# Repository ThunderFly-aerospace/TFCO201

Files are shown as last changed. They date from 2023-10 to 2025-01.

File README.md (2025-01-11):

# TFCO201 - ThunderFly airborne CO2 concentration sensor



The TFCO201 [carbon dioxide gas](https://en.wikipedia.org/wiki/Carbon_dioxide) sensor offers flexible integration options. It can be directly connected to a Pixhawk autopilot with PX4 firmware or used as a sensor for the [TF-ATMON monitoring system](https://www.thunderfly.cz/tf-atmon.html).

Sensors mounted on UAVs can be used for a variety of purposes. TFCO201 can measure CO2 concentrations in parallel with air temperature and humidity, which can be used for meteorological purposes. It could also be used to determine the presence of wildfires.

TFCO201 sensor with cable

## Applications

In combination with the [TF-ATMON system](https://www.thunderfly.cz/tf-atmon.html), the sensor could be used in various applications. Here are a few examples. 

### Atmospheric sounding

The TFCO201 sensor could be used for [direct atmospheric sounding](https://en.wikipedia.org/wiki/Atmospheric_sounding). Here is an example of measured data taken by [TF-G2 autogyro](https://www.thunderfly.cz/tf-g2.html).

### Locating sources of atmospheric pollution (Urban Air Quality Monitoring)

A drone with a CO2 sensor can monitor carbon dioxide levels in densely populated urban areas, such UAVs can collect data on CO2 concentrations across different parts of the city, aiding authorities in identifying and addressing areas with high emissions. This data can be utilized for green space planning, improving urban transportation, and informing residents about air quality.

### Ecosystem Change Observation 
An unmanned system with a CO2 sensor can monitor changes in CO2 levels in various ecosystems, such as forests, wetlands, or agricultural lands. This information is crucial for scientists studying the impact of climate change on different types of environments and aids in predicting future ecological changes or impact mitigation methods. 

### Industrial Emission Control 
Industrial areas often contribute significantly to total CO2 emissions. A UAV with a CO2 sensor can effectively monitor and map emissions from factories, power plants, and other industrial facilities. This data can be used for emission regulation and developing strategies to reduce the carbon footprint of industrial areas.

## Where to get it?

The TFCO201 is commercially available from [ThunderFly s.r.o.](https://www.thunderfly.cz/). For a commercial quotation, contact us by email at sale@thunderfly.cz or shop at our [Tindie store](https://www.tindie.com/stores/thunderfly/).

## Parameters

| Parameter | Value | Description |
|---|---|---|
| Sensing element | [SCD41](https://sensirion.com/media/documents/E0F04247/631EF271/CD_DS_SCD40_SCD41_Datasheet_D1.pdf) | Other possible sensors SCD40, SCD42 |
| Typical accuracy | ± (50 ppm + 5% of reading) | 400 ppm – 2’000 ppm  |
| Humidity measurement accuracy | ± 9 % RH | -10 °C – 60 °C, 0 %RH – 100 %RH  |
| Temperature measurement accuracy | ± 1.5 °C | -10 °C – 60 °C |
| Repeatability | ± 10 ppm |  |
| Operating temperature range| -10 °C – 60 °C |  |
| Operating humidity range| 0 %RH – 100 %RH | |
| I2C connector | 4-pin JST-GH | The second connector could be installed on the opposite side |
| I2C address | 0x62 | can be changed by using the [TFI2CADT01](https://github.com/ThunderFly-aerospace/TFI2CADT01) |
| Storage temperature range| -20 °C - +40 °C |  |
| Operational input voltage | 3.6 - 5.4V | Overvoltage internally protected by zener diode |
| Mass | 3 g | PCB, without cabling |
| Dimensions | 30 x 15 x 6.5 mm |  PCB |
| Weather resistance | IP40 | External connectors fully occupied.  |

## Schematics

Schematics

## Usage in PX4
~~The sensor is currently supported by the PX4 autopilot. Multiple sensors can be connected to one autopilot. The measured data are immediately sent to the ground station and they are also logged in the onboard ulog file.~~

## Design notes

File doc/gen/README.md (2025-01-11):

# PCB

Board size: 30.0x15.0 mm (1.18x0.59 inches)

- This is the size of the rectangle that contains the board
- Thickness: 0.89 mm (35 mils)
- Material: FR4
- Finish: HAL lead-free
- Layers: 2
- Copper thickness: 35 µm

Solder mask: TOP / BOTTOM

- Color: Green

Silk screen: TOP / BOTTOM

- Color: White

Stackup:

| Name | Type | Color | Thickness [µm]| Material | Er | Loss tan |
|---|---|---|---|---|---|---|
| F.SilkS | Top Silk Screen | | | | | |
| F.Mask | Top Solder Mask | Green | 10 | | | |
| F.Cu | copper | | 35 | | | |
| dielectric 1 | core | | 800 | FR4 | 4.5 | 0.020 |
| B.Cu | copper | | 35 | | | |
| B.Mask | Bottom Solder Mask | Green | 10 | | | |
| B.SilkS | Bottom Silk Screen | | | | | |

# Important sizes

Clearance: 0.2 mm (8 mils)

Track width: 0.3 mm (12 mils)

- By design rules: 0.15 mm (6 mils)

Drill: 0.5 mm (20 mils)

- Vias: 0.5 mm (20 mils) [Design: 0.4 mm (16 mils)]
- Pads: 3.0 mm (118 mils)
- The above values are real drill sizes, they add 0.1 mm (4 mils) to plated holes (PTH)

Via: 0.8/0.4 mm (31/16 mils)

- By design rules: 0.4/0.3 mm (16/12 mils)
- Micro via: yes [0.2/0.1 mm (8/4 mils)]
- Buried/blind via: yes
- Total: 28 (thru: 28 buried/blind: 0 micro: 0)

Outer Annular Ring: 0.15 mm (6 mils)

- By design rules: N/A mm (N/A mils)

Eurocircuits class: 4B
- Using min drill 0.5 mm for an OAR of 0.15 mm

# General stats

Components count: (SMD/THT)

- Top: 1/6 (SMD + THT)
- Bottom: 12/0 (SMD)

Defined tracks:

- 0.3 mm (12 mils)
- 0.4 mm (16 mils)
- 0.5 mm (20 mils)
- 1.0 mm (39 mils)

Used tracks:

- 0.3 mm (12 mils) (22) defined: yes
- 0.4 mm (16 mils) (87) defined: yes

Defined vias:

Used vias:

- 0.8/0.4 mm (31/16 mils) (Count: 28, Aspect: 1.1 A) defined: no

Holes (excluding vias):

- 3.0 mm (118 mils) (6)

Oval holes:

Drill tools (including vias and computing adjusts and rounding):

- 0.5 mm (20 mils) (28)
- 3.0 mm (118 mils) (6)

Solder paste stats:

Using a paste with 87.75 % alloy, that has an specific gravity for the alloy of 7.4 g/cm³
and 1.0 g/cm³ for the flux. This paste has an specific gravity of  4.15 g/cm³.

The stencil thickness is  0.12 mm.

| Side | Pads with paste | Area [mm²] | Paste [g] |
|---|---|---|---|
| Top | 6 | 9.28 | 0.05 |
| Bottom | 53 | 75.30 | 0.37 |
| Total  | 59 | 84.58 | 0.42 |

Note: this is just an approximation to the theoretical value. Margins of the solder mask and waste aren't computed.

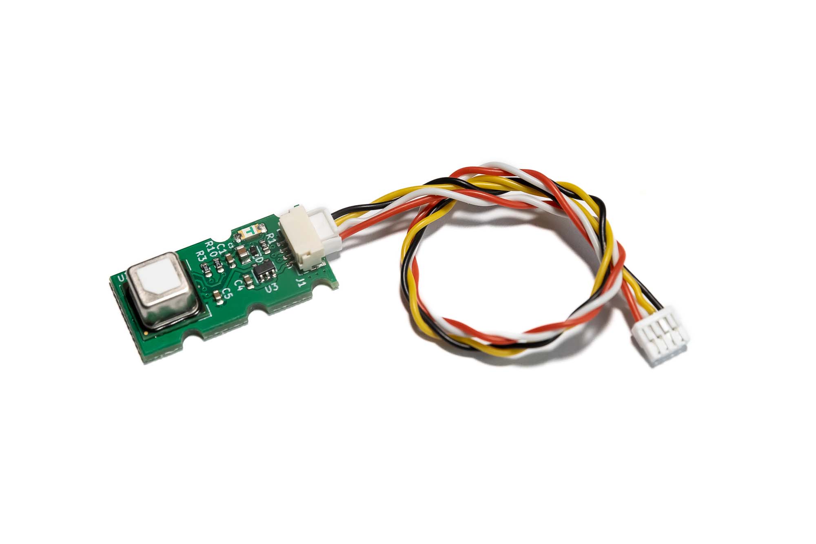
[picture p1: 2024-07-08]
doc/img/TFCO201-small.jpg

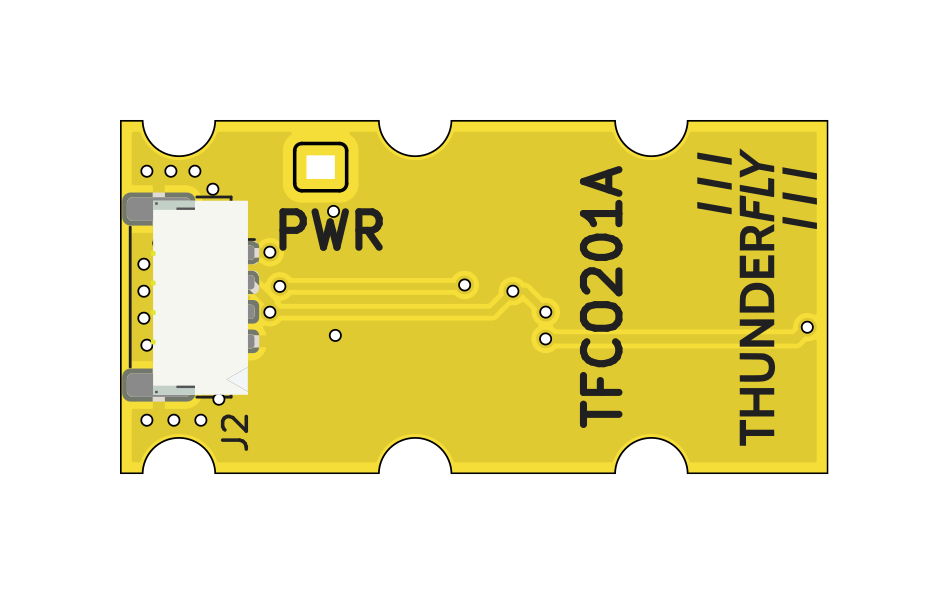
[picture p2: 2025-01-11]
doc/gen/img/TFCO201-top.png

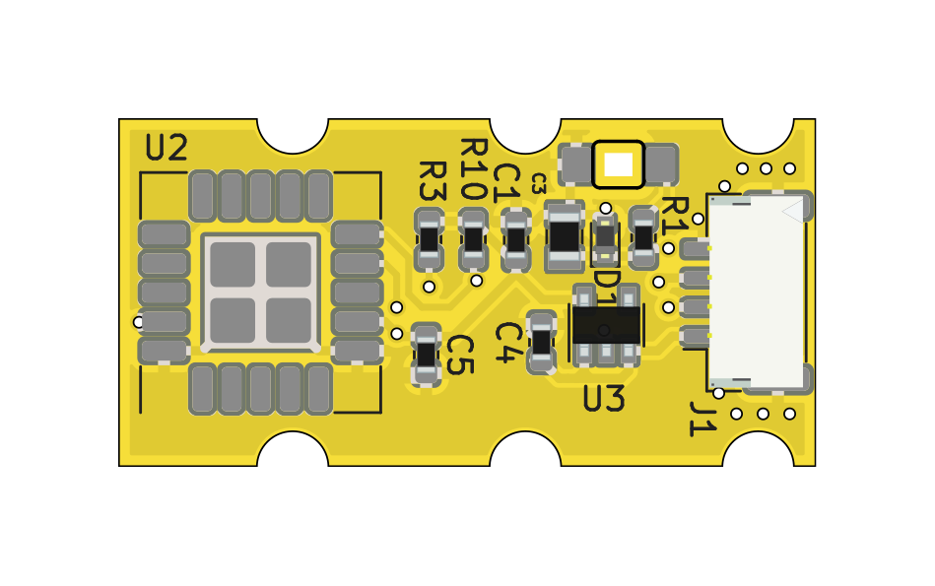
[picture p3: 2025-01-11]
doc/gen/img/TFCO201-bottom.png

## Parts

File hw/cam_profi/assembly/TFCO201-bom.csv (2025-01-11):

Component | Description | Part | References | Value | Footprint | Quantity Per PCB | Datasheet | ust_id
1 | Unpolarized capacitor | C | C4C5 | 100nF | SMD-0603 | 2 | ~ | 5c70984812875079b91f8bf2
2 | Unpolarized capacitor | C | C1 | 1uF | SMD-0603 | 1 | ~ | 5c70984812875079b91f8bc2
3 | Unpolarized capacitor | C | C3 | 10uF | SMD-0805 | 1 | ~ | 5c70984812875079b91f8bbd
4 |  | D_ZENER | D1 | BZX585-B5V6.115 | D_SOD-523 | 1 |  | 60879d38128750769ee58e48
5 | Light emitting diode | LED | D2 | LED GREEN | LED_1206_mill | 1 | ~ | 5c70984412875079b91f8895
6 |  | SM04B-GHS-TB | J1J2 | SM04B-GHS-TB | JST_GH_SM04B-GHS-TB_1x04-1MP_P1.25mm_Horizontal | 2 |  | 5c86273d1287500b4e0280be
7 | Resistor | R | R1 | 180R | SMD-0603 | 1 | ~ | 5c70984512875079b91f8957
8 | Resistor | R | R3R10 | 10k | SMD-0603 | 2 | ~ | 5c70984512875079b91f8962
9 | 300mA Low-dropout Voltage Regulator, Vout 3.3V, Vin up to 5.5V, SOT-23 | MIC5504-3.3YM5 | U3 | MIC5504-3.3YM5 | SOT-23-5 | 1 | http://ww1.microchip.com/downloads/en/DeviceDoc/MIC550X.pdf | 5c7255e81287500b4e112ea2
10 | Photoacoustic CO2 sensor, 40 000 ppm, I2C, 2.4-5.5 V, High accuracy 400 - 5000 ppm | SCD41-D-R2 | U2 | SCD41-D-R2 | Sensirion_SCD4x-1EP_10.1x10.1mm_P1.25mm_EP4.8x4.8mm | 1 | https://sensirion.com/media/documents/E0F04247/631EF271/CD_DS_SCD40_SCD41_Datasheet_D1.pdf

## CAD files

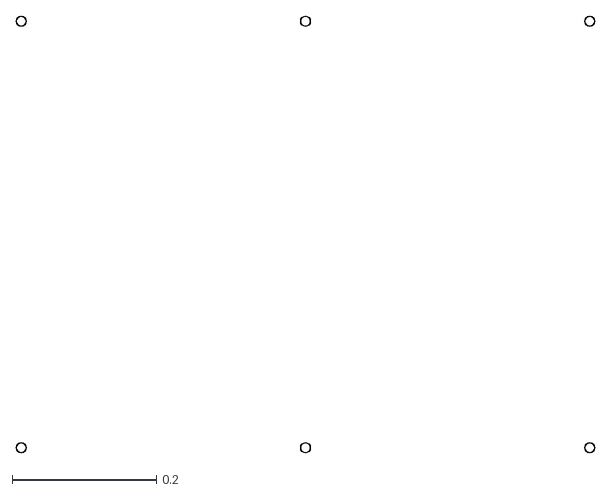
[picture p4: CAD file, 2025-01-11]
doc/gen/dxf/TFCO201-Margin.dxf
0.801 x 0.604

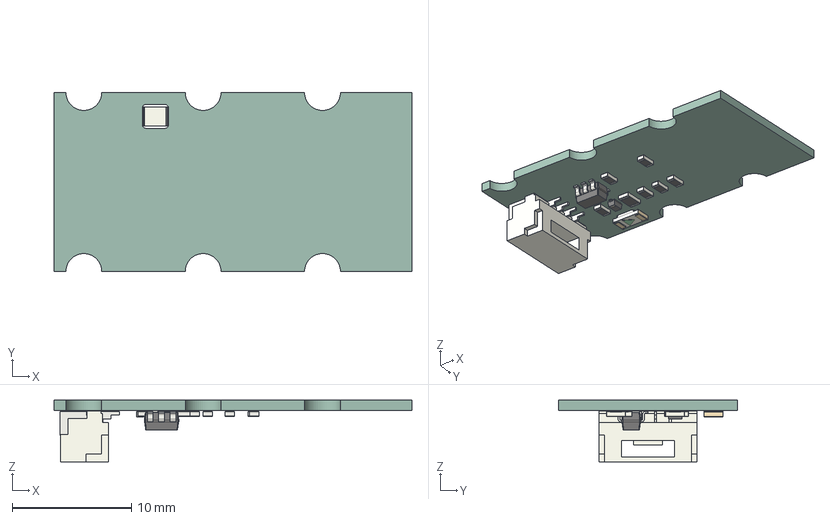
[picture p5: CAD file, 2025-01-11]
doc/gen/TFCO201.step
30.0 x 15.0 x 5.18 mm
LED_1206_3216Metric
R_0603_1608Metric x 6
D_SOD_523
JST_SM04B_GHS_TB
R_0805_2012Metric
SOT_23_5
kibot_szv15d0n_PCB

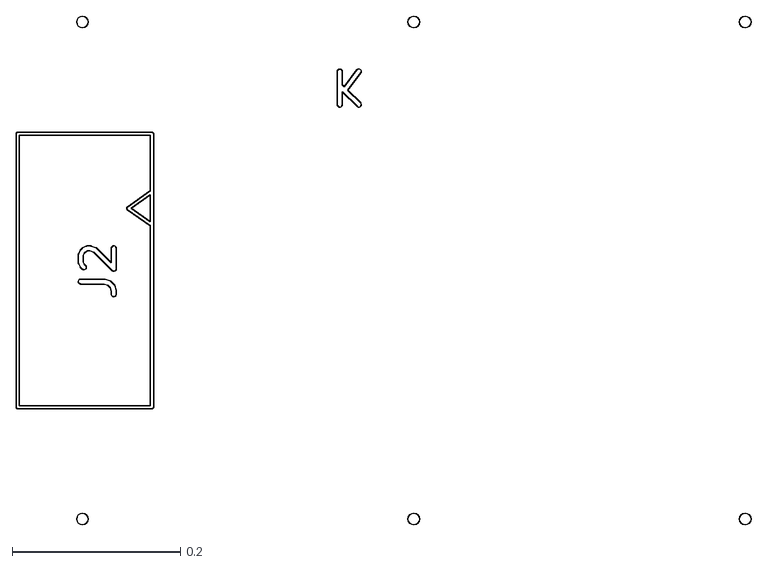
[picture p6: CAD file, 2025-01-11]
doc/gen/dxf/TFCO201-F_Fab.dxf
0.873 x 0.604

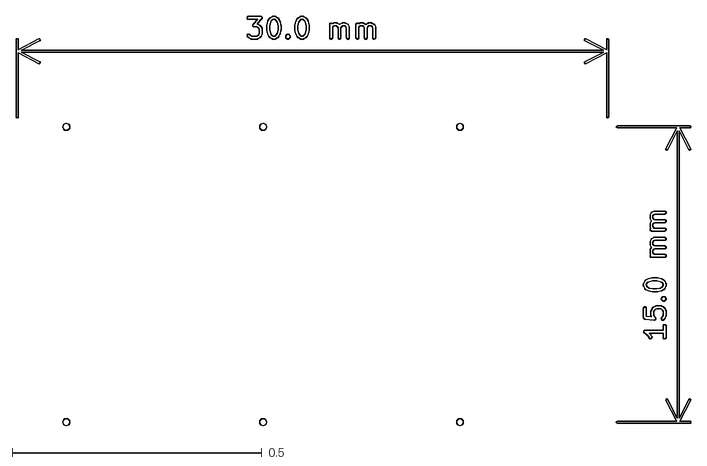
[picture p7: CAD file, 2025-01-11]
doc/gen/dxf/TFCO201-User_Drawings.dxf
1.35 x 0.818

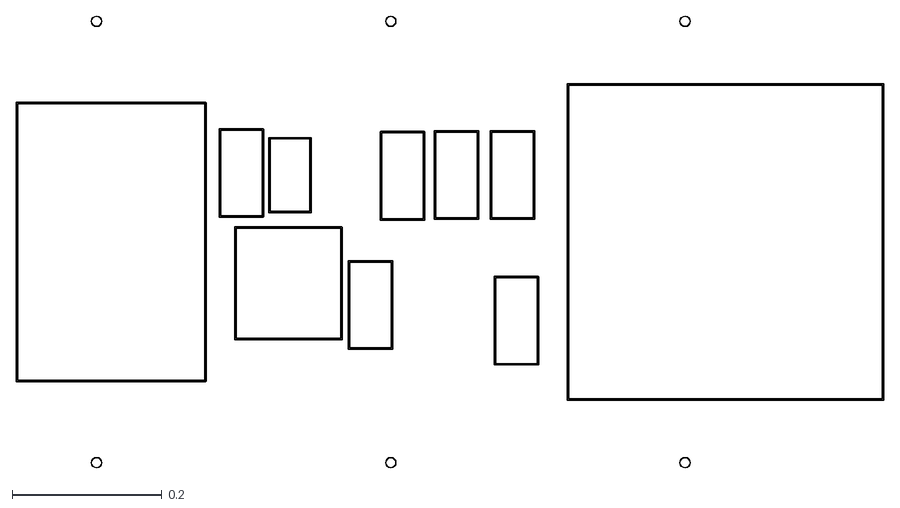
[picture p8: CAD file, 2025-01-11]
doc/gen/dxf/TFCO201-B_Courtyard.dxf
1.16 x 0.604

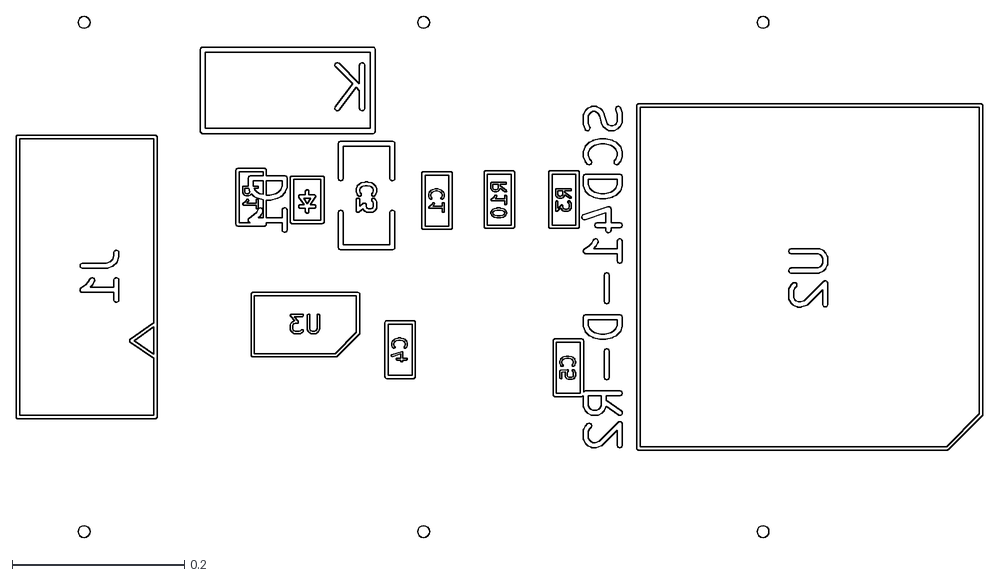
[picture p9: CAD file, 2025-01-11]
doc/gen/dxf/TFCO201-B_Fab.dxf
1.12 x 0.604

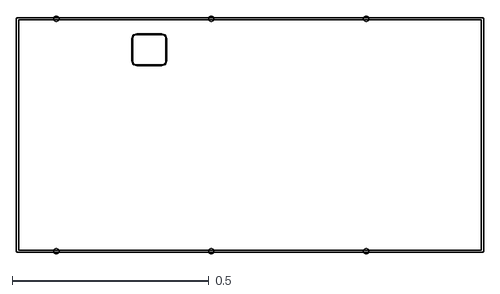
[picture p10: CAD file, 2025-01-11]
doc/gen/dxf/TFCO201-Edge_Cuts.dxf
1.19 x 0.604

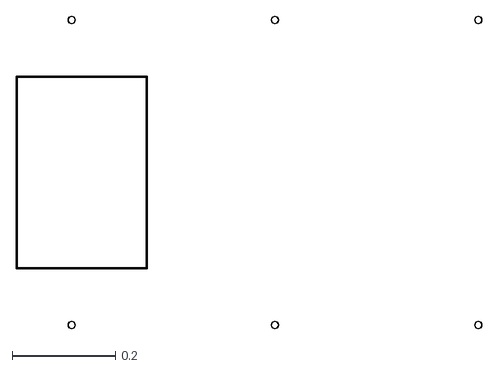
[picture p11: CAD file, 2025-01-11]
doc/gen/dxf/TFCO201-F_Courtyard.dxf
0.902 x 0.604

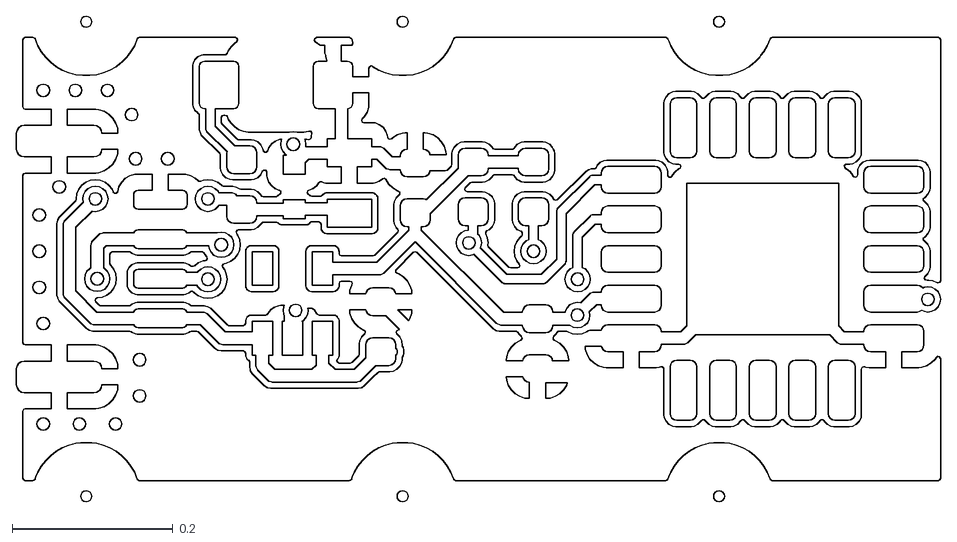
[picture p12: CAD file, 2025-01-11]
doc/gen/dxf/TFCO201-B_Cu.dxf
1.15 x 0.604

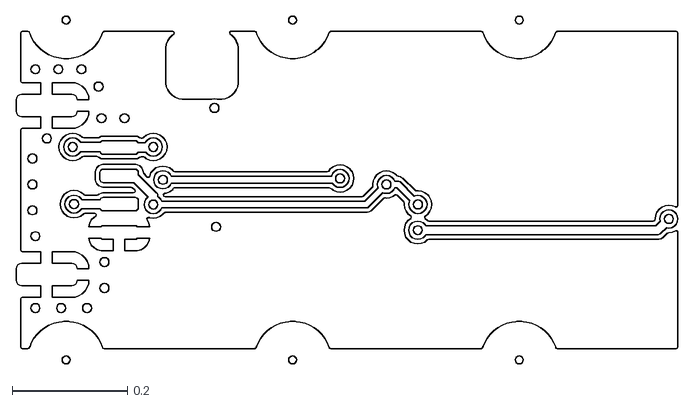
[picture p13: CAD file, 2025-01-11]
doc/gen/dxf/TFCO201-F_Cu.dxf
1.15 x 0.604

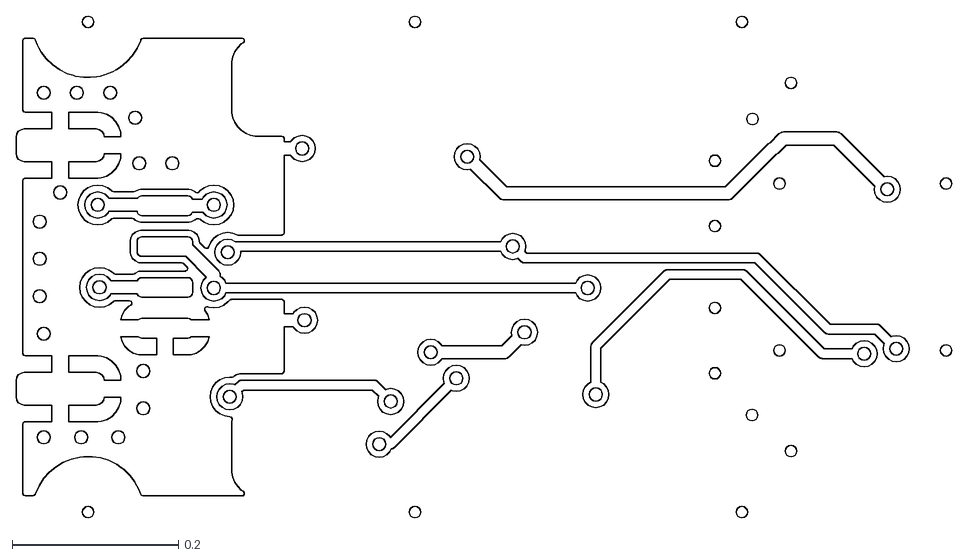
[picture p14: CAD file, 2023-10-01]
doc/gen/dxf/TFHT01-F_Cu.dxf
1.13 x 0.604

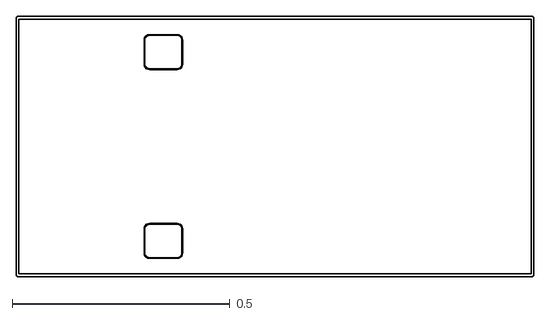
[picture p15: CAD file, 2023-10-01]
doc/gen/dxf/TFHT01-Edge_Cuts.dxf
1.19 x 0.596

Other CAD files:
doc/gen/dxf/TFCO201-B_Mask.dxf
doc/gen/dxf/TFCO201-B_Paste.dxf
doc/gen/dxf/TFCO201-B_Silkscreen.dxf
doc/gen/dxf/TFCO201-F_Mask.dxf
doc/gen/dxf/TFCO201-F_Paste.dxf
doc/gen/dxf/TFCO201-F_Silkscreen.dxf
doc/gen/dxf/TFHT01-B_Mask.dxf
doc/gen/dxf/TFHT01-B_Silkscreen.dxf
doc/gen/dxf/TFHT01-F_Silkscreen.dxf

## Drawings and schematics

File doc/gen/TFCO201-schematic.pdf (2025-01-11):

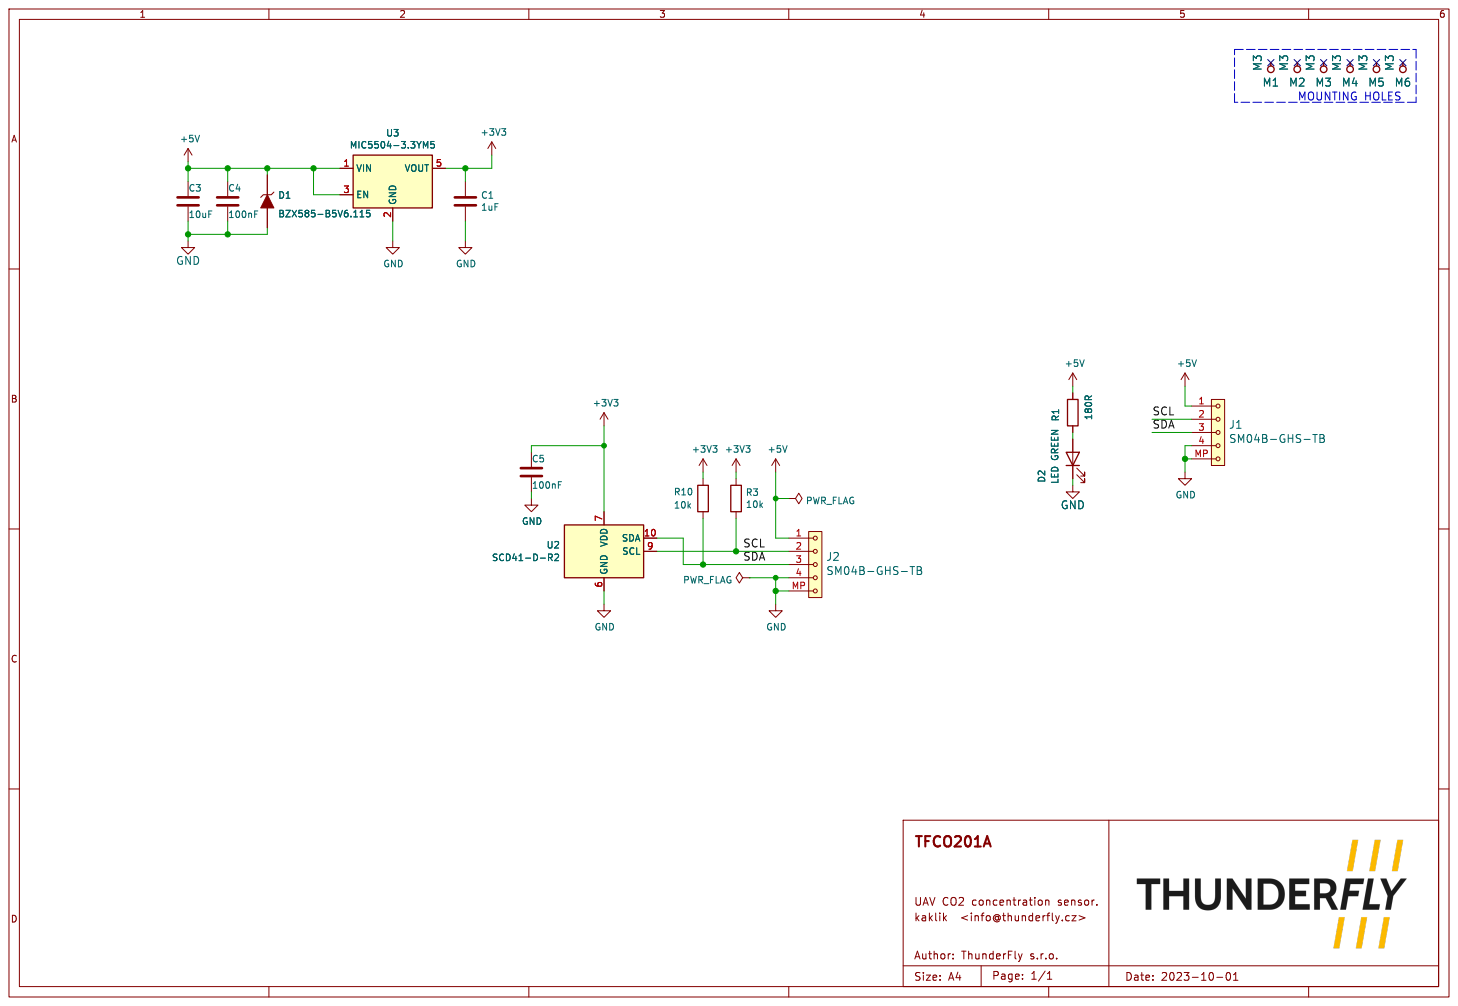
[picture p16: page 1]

7 SCL 9 GND R1180R D2 LED GREEN

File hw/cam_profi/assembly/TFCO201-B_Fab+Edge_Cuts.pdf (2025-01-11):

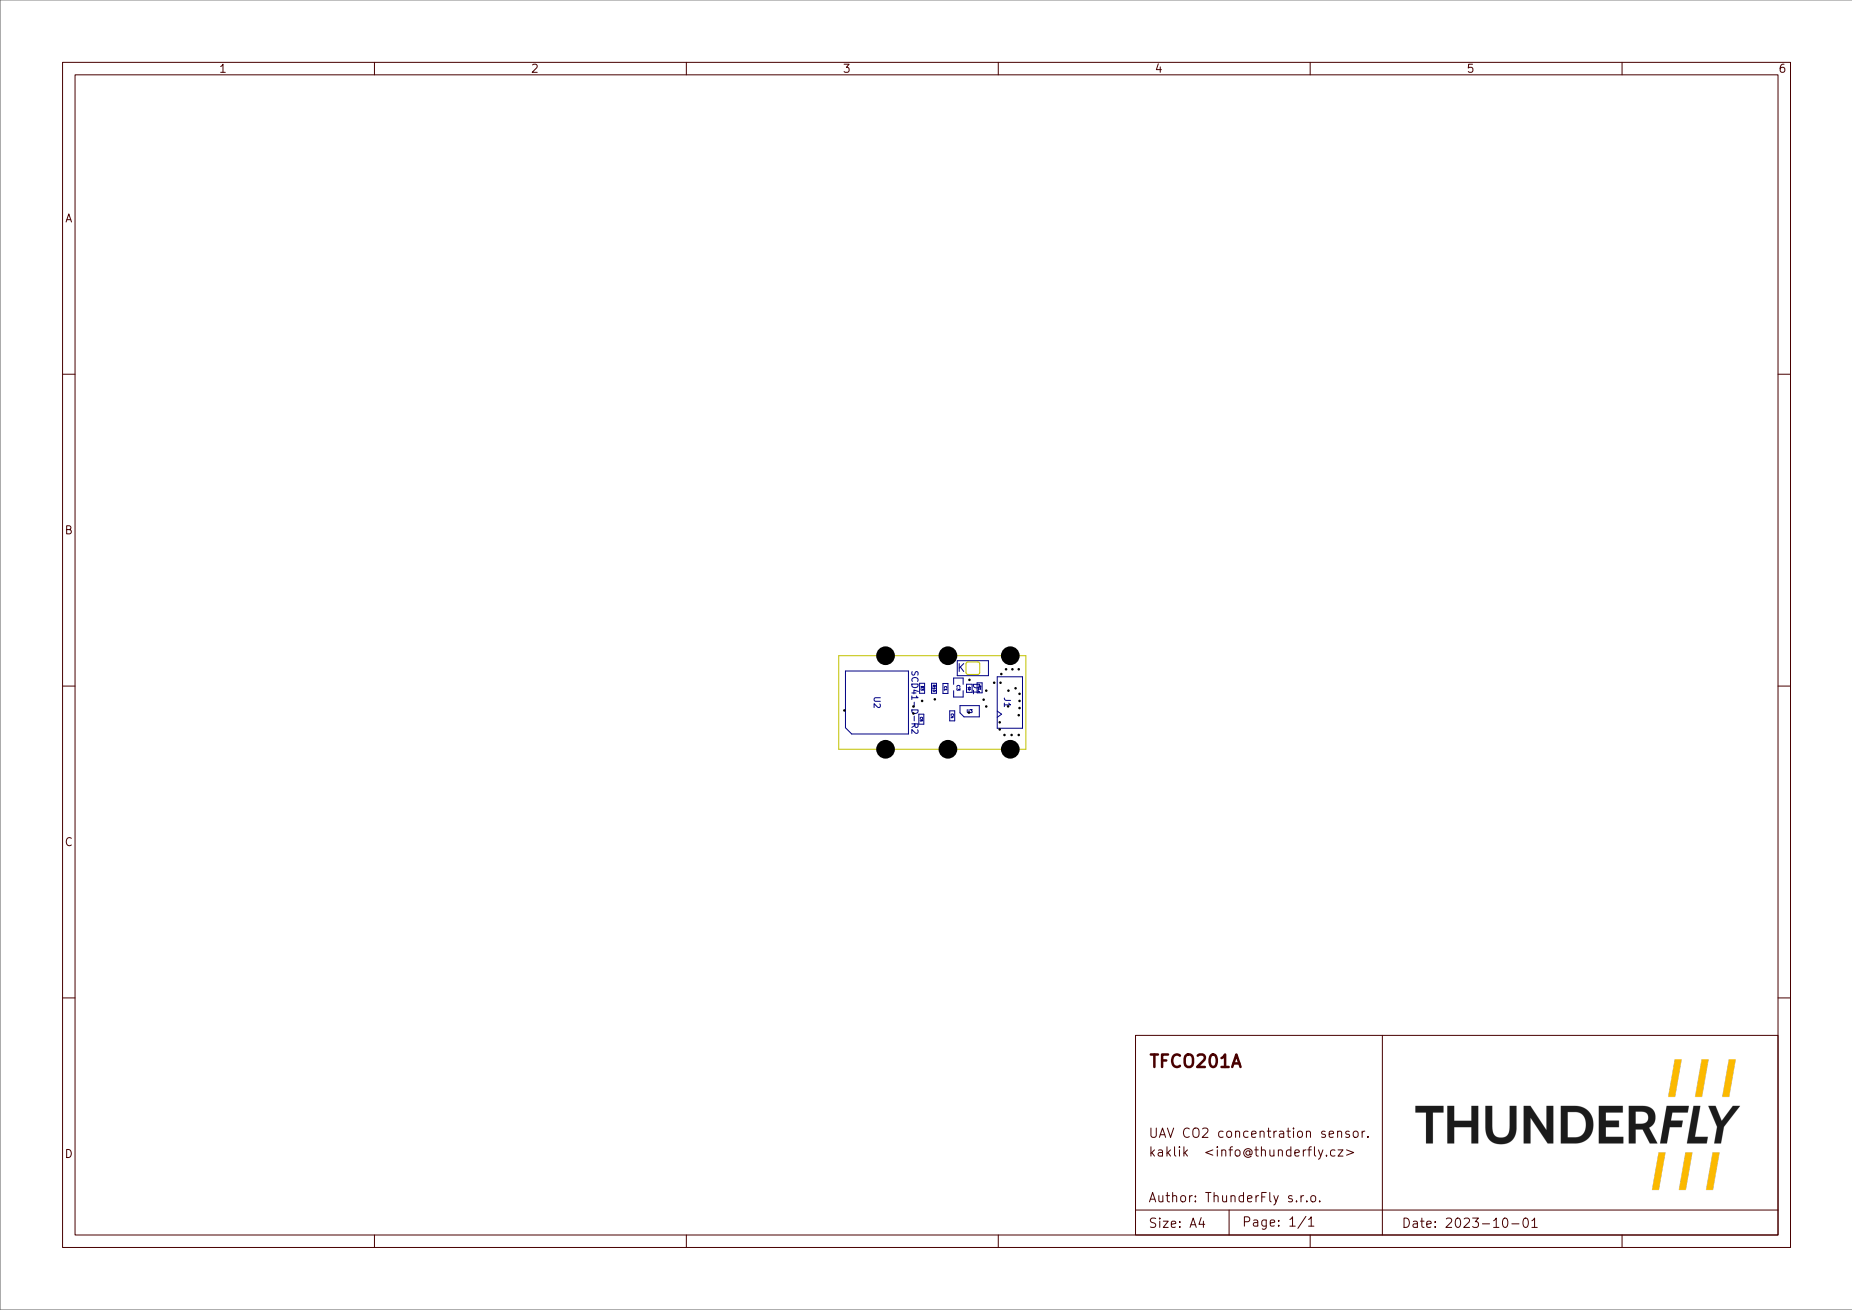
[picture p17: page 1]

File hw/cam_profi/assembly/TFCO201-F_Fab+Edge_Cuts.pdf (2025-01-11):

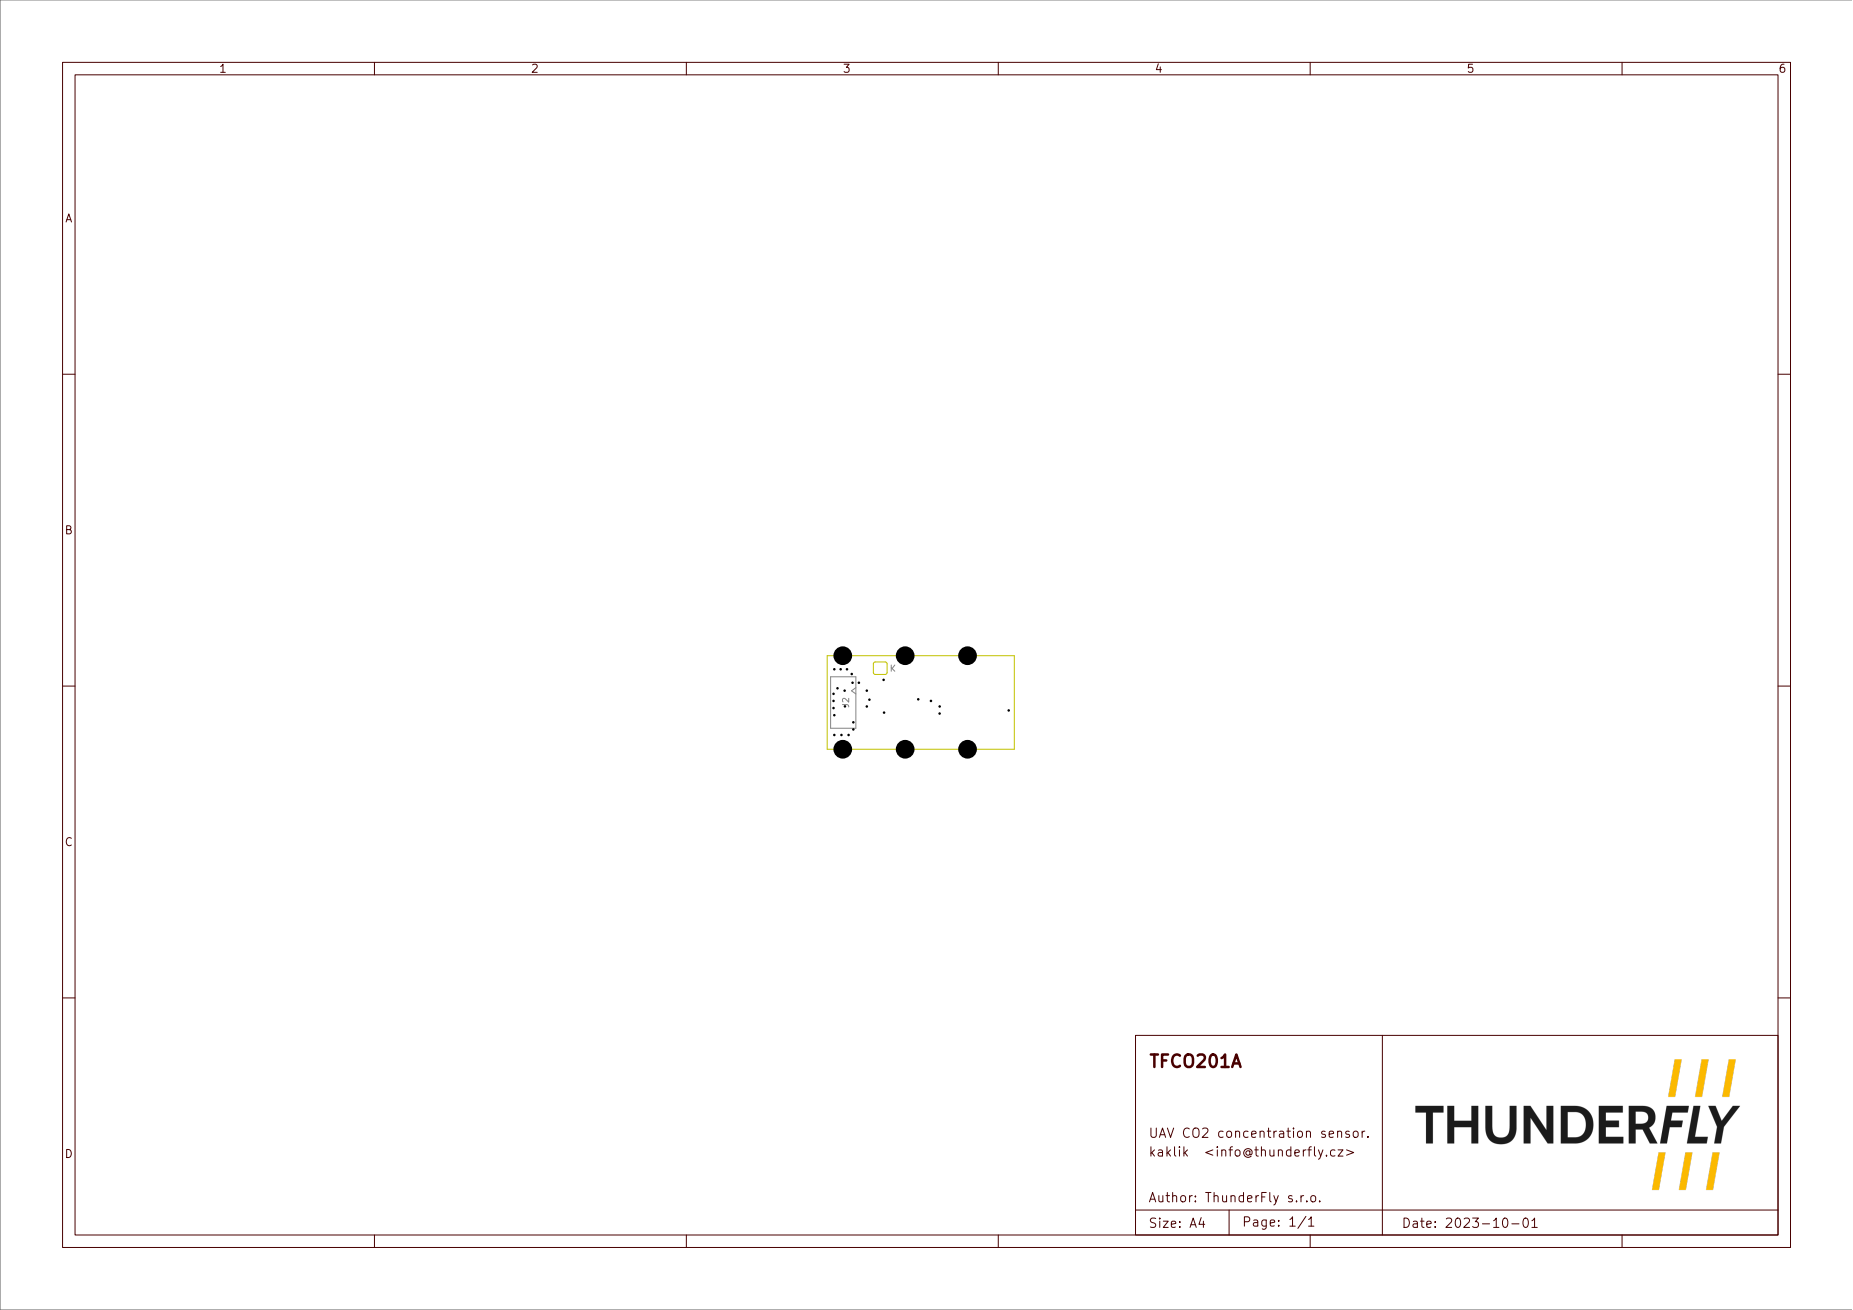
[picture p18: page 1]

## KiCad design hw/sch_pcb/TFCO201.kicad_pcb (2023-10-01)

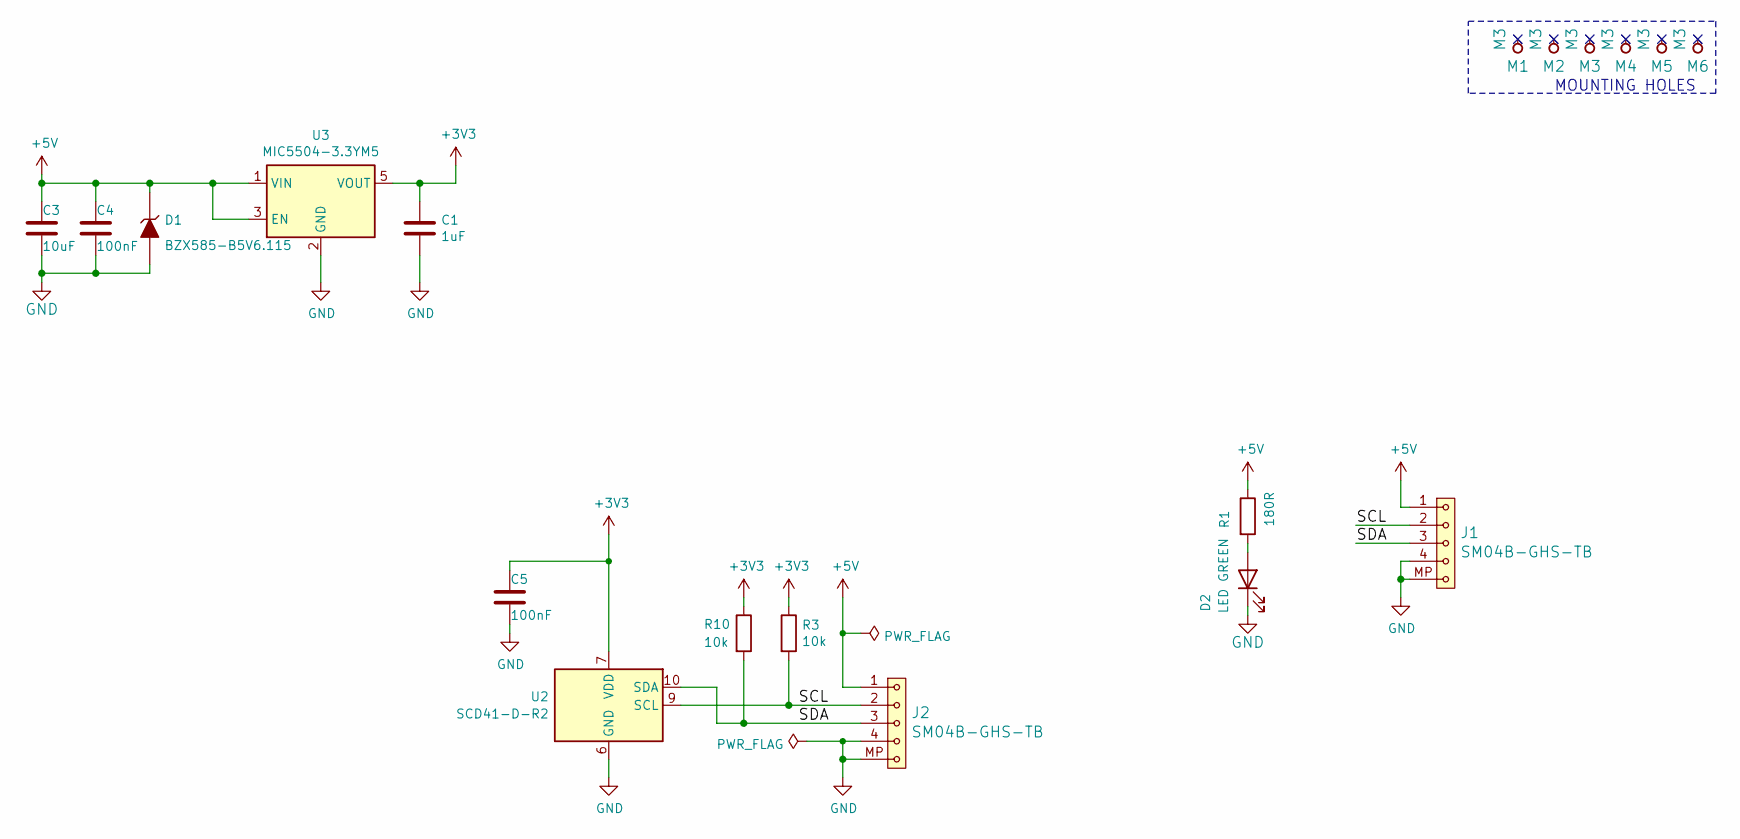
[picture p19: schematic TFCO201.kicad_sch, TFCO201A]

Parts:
C1: 1uF; SMD-0603
C3: 10uF; SMD-0805
C4, C5: 100nF; SMD-0603
D1: BZX585-B5V6.115; D_SOD-523
D2: LED GREEN; LED_1206_mill
J1, J2: SM04B-GHS-TB; JST_GH_SM04B-GHS-TB_1x04-1MP_P1.25mm_Horizontal
M1, M2, M3, M4, M5, M6: M3; dira_3mm
R1: 180R; SMD-0603
R3, R10: 10k; SMD-0603
U2: SCD41-D-R2; Sensirion_SCD4x-1EP_10.1x10.1mm_P1.25mm_EP4.8x4.8mm
U3: MIC5504-3.3YM5; SOT-23-5

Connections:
+3V3: C1.1, C5.1, R3.1, R10.1, U2.7 (VDD), U2.19 (VDD), U3.5 (VOUT)
+5V: C3.1, C4.1, D1.1 (K), J1.1, J2.1, R1.1, U3.1 (VIN), U3.3 (EN)
/SCL: J1.2, J2.2, R3.2, U2.9 (SCL)
/SDA: J1.3, J2.3, R10.2, U2.10 (SDA)
GND: C1.2, C3.2, C4.2, C5.2, D1.2 (A), D2.1 (K), J1.4, J1.MP, J2.4, J2.MP, U2.6 (GND), U2.20 (GND), U2.21 (GND), U3.2 (GND)
unnamed: D2.2 (A), R1.2

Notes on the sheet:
MOUNTING HOLES

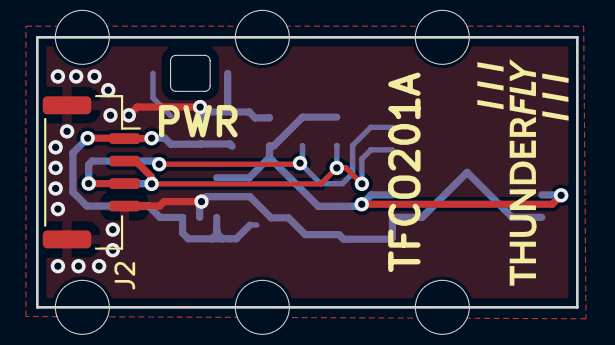
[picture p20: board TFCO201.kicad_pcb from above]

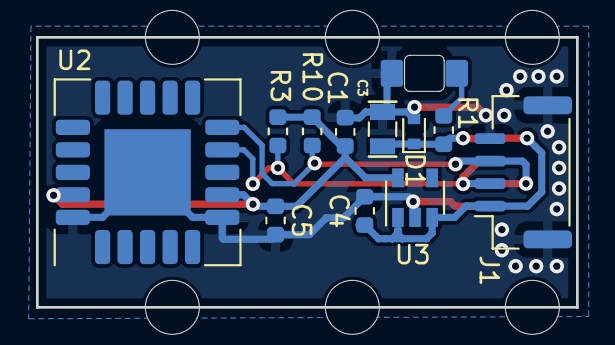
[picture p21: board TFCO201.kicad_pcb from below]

Board: 2 copper layers, 30.0 x 15.0 mm, 19 parts (12 on the bottom side), 6 nets.

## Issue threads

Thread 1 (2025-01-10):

Fix wrong cable colors coding in the title photo

kaklik, 2025-01-10:
The title photo uses UAVCAN cable colors instead of I2C cable color coding.

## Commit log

2023-10-01 Initial version of ThunderFly CO2 sensor.
    [TFCO201.kicad_pcb, TFCO201.kicad_sch, TFHT01-bom.csv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]
2023-10-01 Update README.md
    Modify the readme to the current sensor version.
2023-10-01 Update actions products
    [TFCO201-B_Courtyard.dxf, TFCO201-B_Cu.dxf, TFCO201-B_Fab.dxf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]
2023-10-01 Update title block.
    [TFCO201.kicad_pcb, TFCO201.kicad_sch]
